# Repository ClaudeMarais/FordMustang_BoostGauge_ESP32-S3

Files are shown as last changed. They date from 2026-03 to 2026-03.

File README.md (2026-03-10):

# Boost Guage for Ford Mustang using ESP32-S3
 
An Arduino project boost gauge for a 2016 Ford Mustang Ecoboost. OBD2 data is used to display turbo boost pressure, current gear, vehicle speed and a shift indicator graph.

NOTE: It's recommended to disconnect the device if the car won't be driven for more than a week.

Car data like boost pressure, RPM, vehicle speed and current gear can be retrieved from the car's high speed CAN bus via the OBD2 port. The ESP32-S3 has a built-in CAN controller, so we connect a SN65HVD230 CAN bus transceiver to the ESP32-S3 which communicates on the high speed bus. Showing something on a display is a blocking operation, i.e. while the display is updating, you can't collect the latest car data. Luckily the ESP32-S3 has two cores, therefore we use one core to continuously read CAN frames with car data while updating the display on the other core.

The OBD2 connector has an always-on 12V pin where the device will be powered from. Since it's always on, it will unnecessarily draw power when the car is turned off. One option would be to just always unplug the device when not driving, another might be to add a button to the device to manually switch it on/off. In this project, we simply detect if the car is turned on and if not, we put the device into a lite sleep mode by reducing the processor clock speed to 40Mhz and switching off the display using a mosfet. For some reason switching in and out of actual deep sleep mode drains the car's battery, it's probably waking up some electronic components in the car? When we detect that the car is on, the processor is switched back to 240MHz and the dispay is switched on again.

Below is some power information when the device is connected together with a BAMA ECU tuner logger device, which also draws power and monitors when the car switches on.

| Microcontroller Setup | Power | Notes  | 
| ---|---|---|
| 240MHz with the display on | 125mA @ 5.12V  | |
| 240MHz with display off | 38mA @ 5.1V | |
| 80Mhz with display off | 29mA @ 5.1V | | 
| 40Mhz with display off | 22mA @ 5.1V | SN65HVD230 requires 80Mhz to operate reliably  | 
| 40/80MHz cycle (3s at 40MHz, 1s at 80MHz) | ~24mA avg @ 5V | Current idle mode |
| Deepsleep with display off | ~7mA @ 5.12V | Drains car battery 0.18V per hour | 

Estimated daily drain from the car's 12V battery (assuming 85% buck converter efficiency):

| Mode | 5V current | 12V current | Daily drain | Days to 50% (60Ah battery) |
|---|---|---|---|---|
| 240 MHz display off | 38 mA | 18.6 mA | 447 mAh | 67 days |
| 80 MHz constant | 29 mA | 14.2 mA | 341 mAh | 88 days |
| 40 MHz constant | 22 mA | 10.8 mA | 259 mAh | 116 days |
| 40/80 MHz cycle (current) | ~24 mA | 11.6 mA | 279 mAh | 107 days |

NOTE: It's fun to tinker with your car, but there is always a chance to mess things up. I won't be liable if for some reason you damage your car.

NOTE: The CAN IDs used in this project specifically work with a 2016 Ford Mustang Ecoboost. The same IDs might not work on other models, you'll have to research what PIDs work with your own car.

Some tips:
 - Diagrams of OBD2 pins are normally shown for the female connector in your car. Don't forget that those pins are in swapped/mirrored positions on the male connector.
 - The OBD2 connector has an "always on" 12V pin. Make sure the wire connecting to that pin on your male connector isn't exposed so that it cannot touch other wires!
 - I tried multiple pins on the ESP32-S3 to connect to the SN65HVD230, but only D4/D5 worked for me. Coincidentally these are also the SDA/SCL pins.
 
Hardware:
 - XIAO ESP32-S3
 - 12V to 5V Voltage regulator
 - SN65HVD230 CAN bus transceiver
 - ILI9341V SPI display, 2.8 inch 240x320 Capacitive Touch Screen
 - AO3401 A19T P-Channel Mosfet (30V 4.2A RDS 50mΩ)
 - 220 Ohm Resistor
 - 2.2K Ohm Resistor
 - Magnetic Pogo Pin Connector
 - OBD2 Connector
 - USB Data Cable
 
Arduino libraries used:
 - ESP32-TWAI-CAN: https://github.com/handmade0octopus/ESP32-TWAI-CAN
 - ArduinoGFX: https://github.com/moononournation/Arduino_GFX

If you are unfamiliar with Arduino, it’s pretty simple and there is a multitude of small tutorials on the internet. At a high level, you will need to:
-	Install the Arduino IDE - https://www.arduino.cc/en/software
-	Configure Arduino IDE for ESP32 - https://randomnerdtutorials.com/installing-esp32-arduino-ide-2-0/
-	Install the two libraries mentioned above - https://docs.arduino.cc/software/ide-v1/tutorials/installing-libraries/
-	Try out the most simple ESP32-S3 app to switch on its onboard LED - https://youtu.be/JlnV3U3Rx7k?si=xF3rMG3LD-cYAaQe

--------------------------------

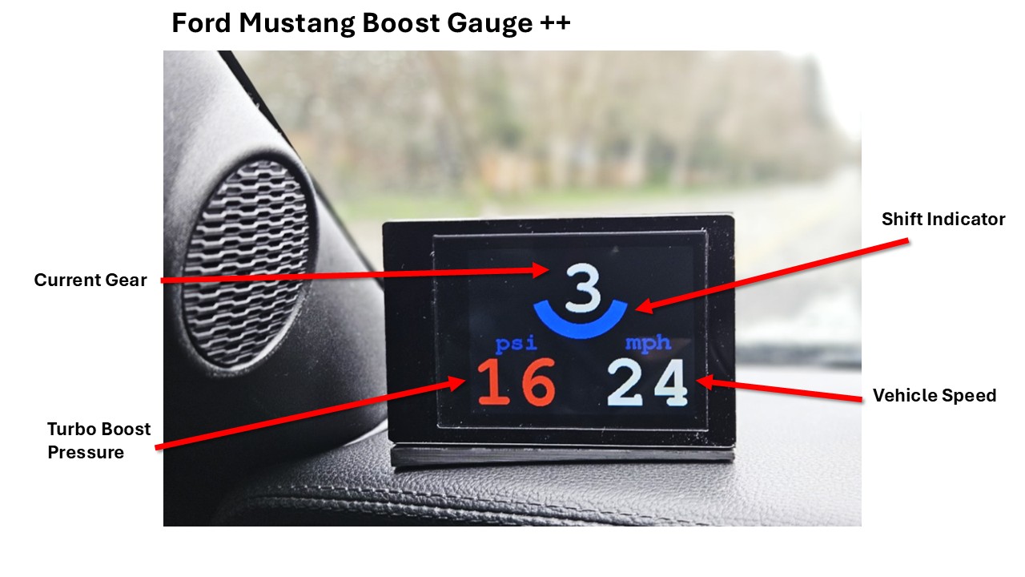
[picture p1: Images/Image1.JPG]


--------------------------------

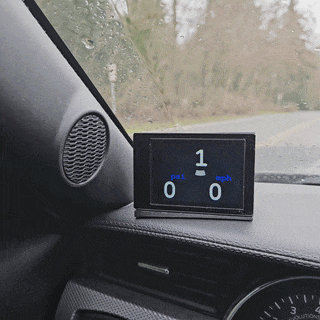
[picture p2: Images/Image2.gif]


--------------------------------

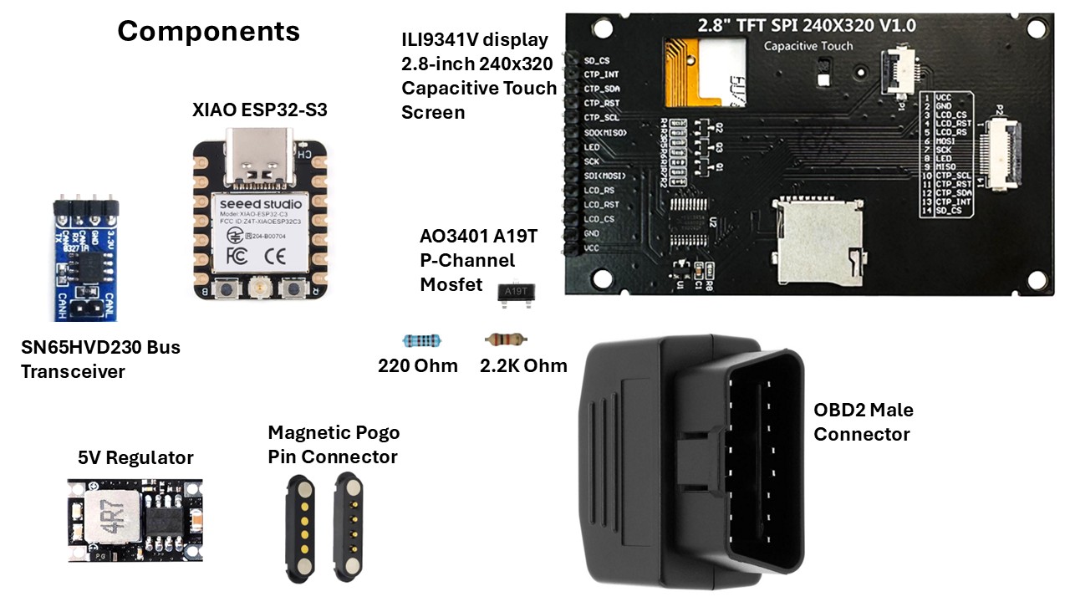
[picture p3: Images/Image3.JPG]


--------------------------------

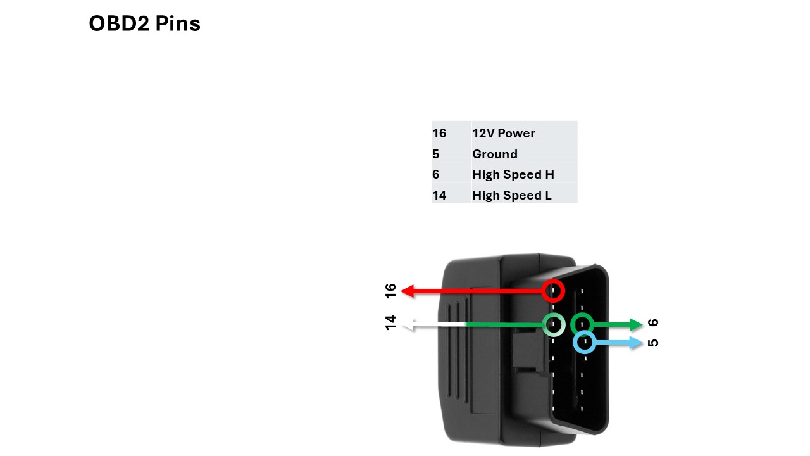
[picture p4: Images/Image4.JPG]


--------------------------------

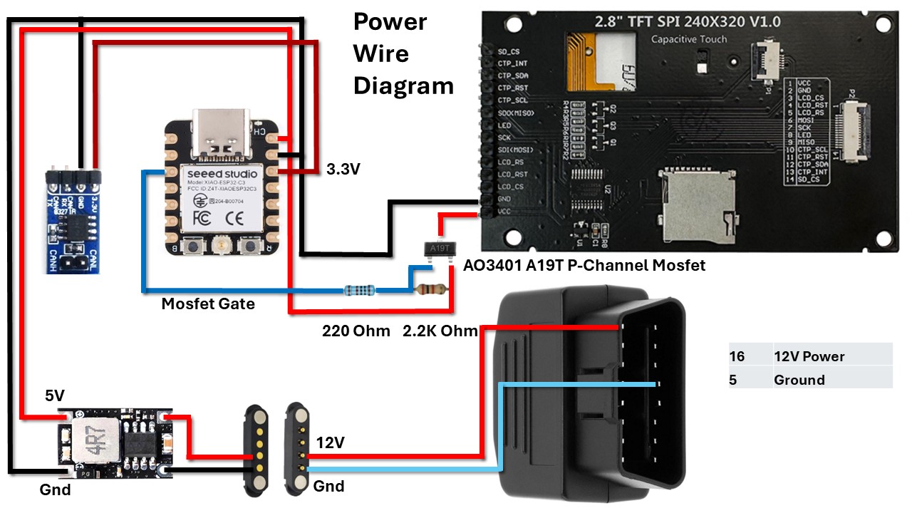
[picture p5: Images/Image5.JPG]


--------------------------------

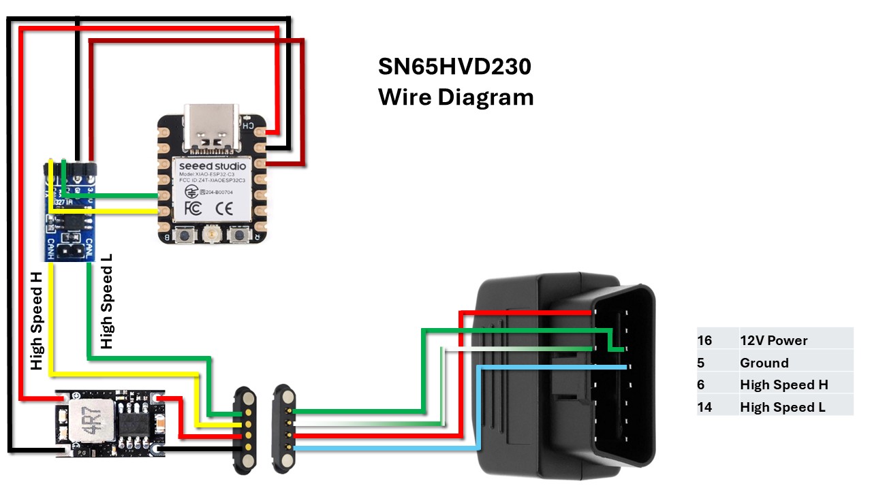
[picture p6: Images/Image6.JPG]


--------------------------------

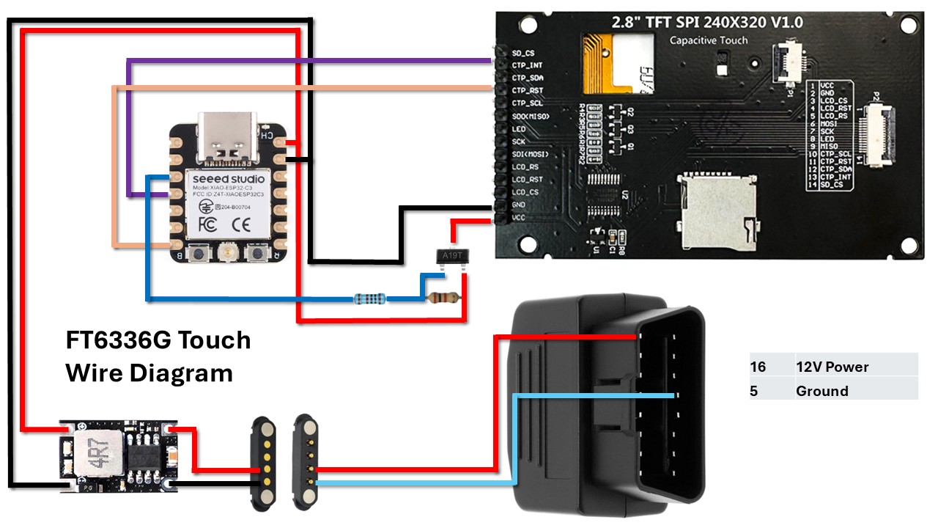
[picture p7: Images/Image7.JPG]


--------------------------------

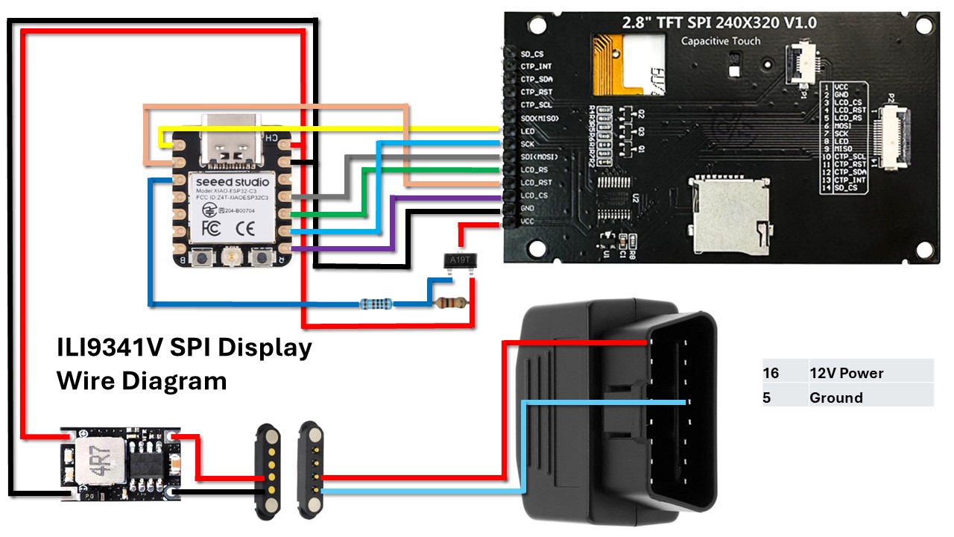
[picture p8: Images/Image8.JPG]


--------------------------------

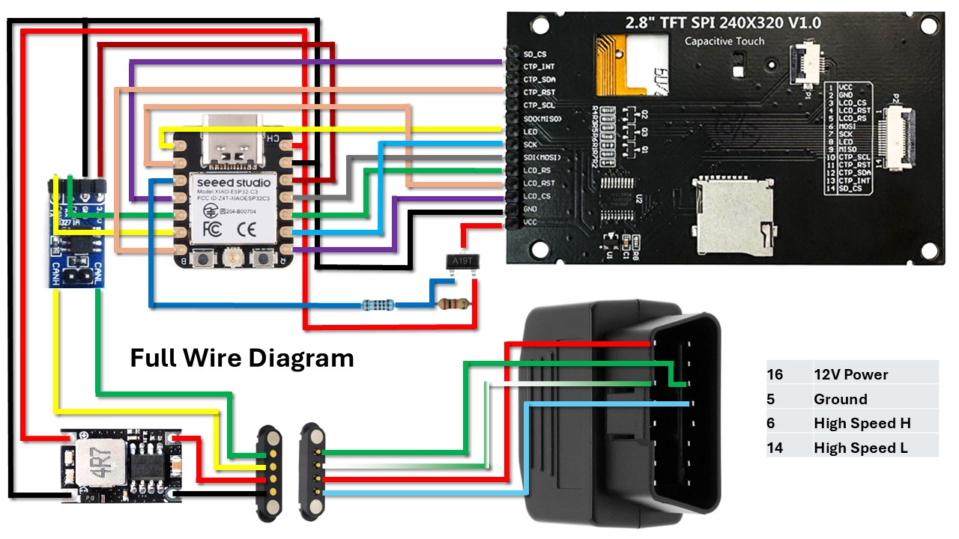
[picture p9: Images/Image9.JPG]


--------------------------------

You will need about 1.5m of wiring to reach from the car's OBD2 connector up to the windshield of the car. Only four OBD2 wires are required to reach the device, two for power and two for the high speed CAN bus communication. I used three different cables for this. First, an OBD2 splitter so that another device, e.g. a tuner device, can be attached while this device is used. Then I soldered a long USB data cable to the OBD2 connector cable. Make sure that you specifically buy a data cable and not a charging cable, since a charging cable won’t have extra data wires.

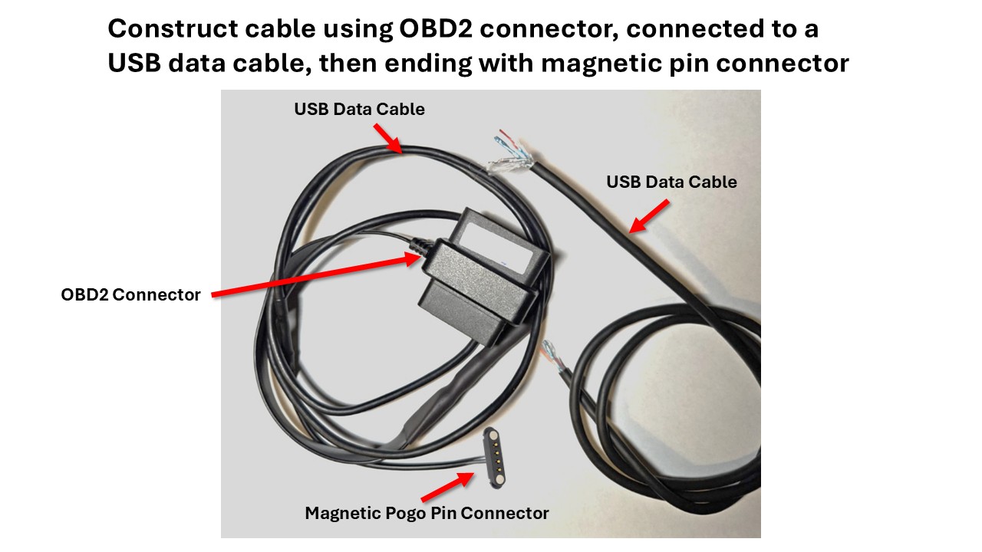
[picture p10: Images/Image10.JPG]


--------------------------------

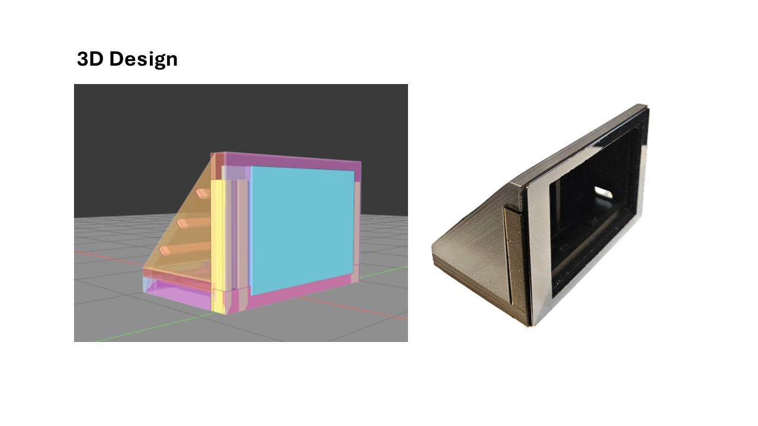
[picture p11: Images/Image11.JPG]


--------------------------------

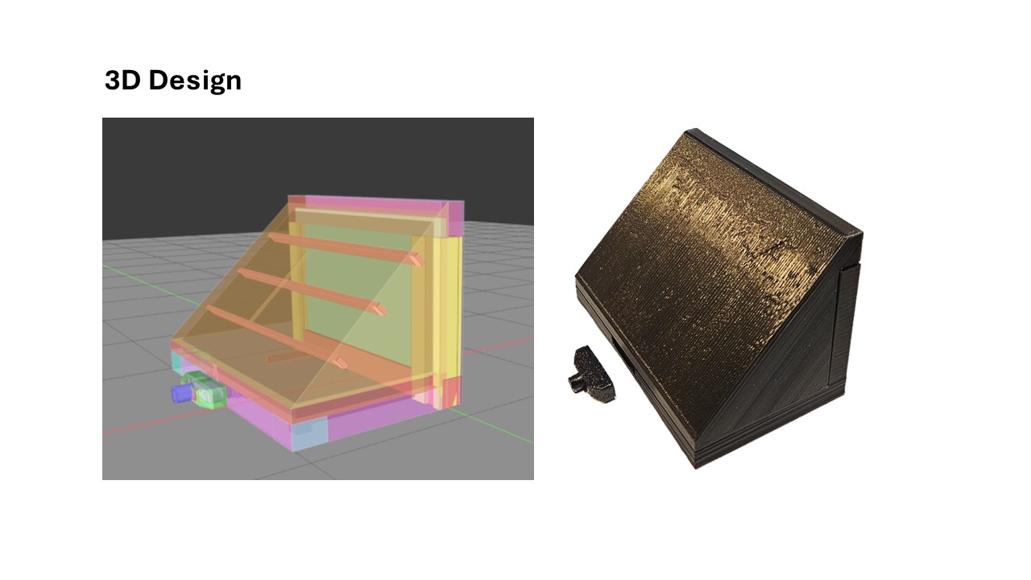
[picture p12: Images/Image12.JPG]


--------------------------------

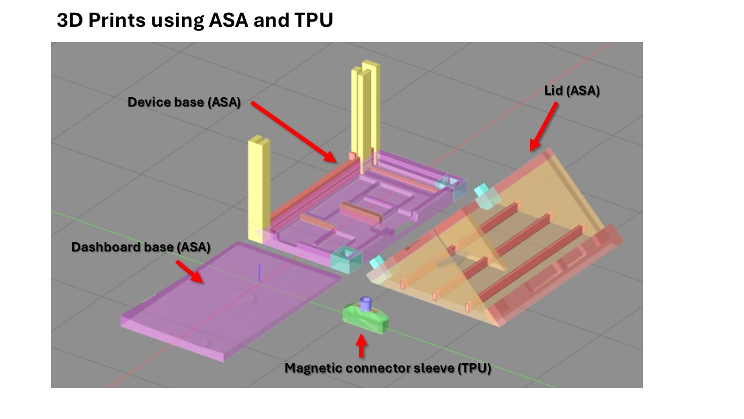
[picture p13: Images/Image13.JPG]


--------------------------------

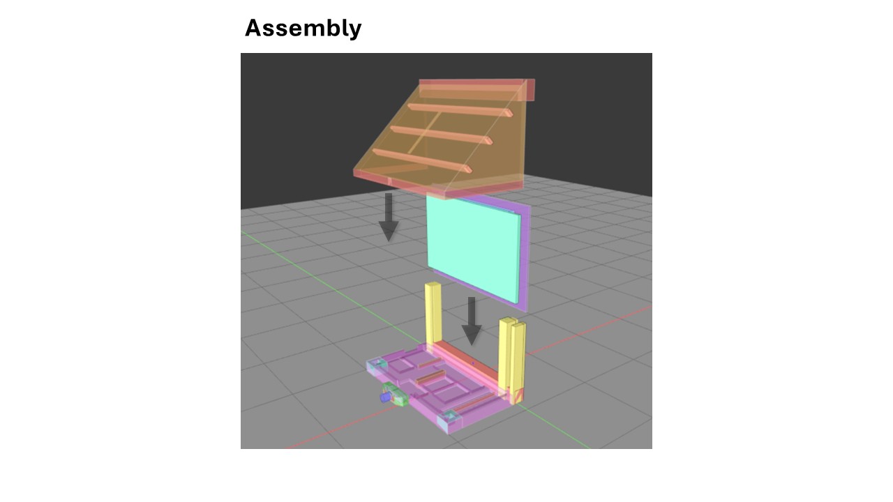
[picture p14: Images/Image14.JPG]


--------------------------------

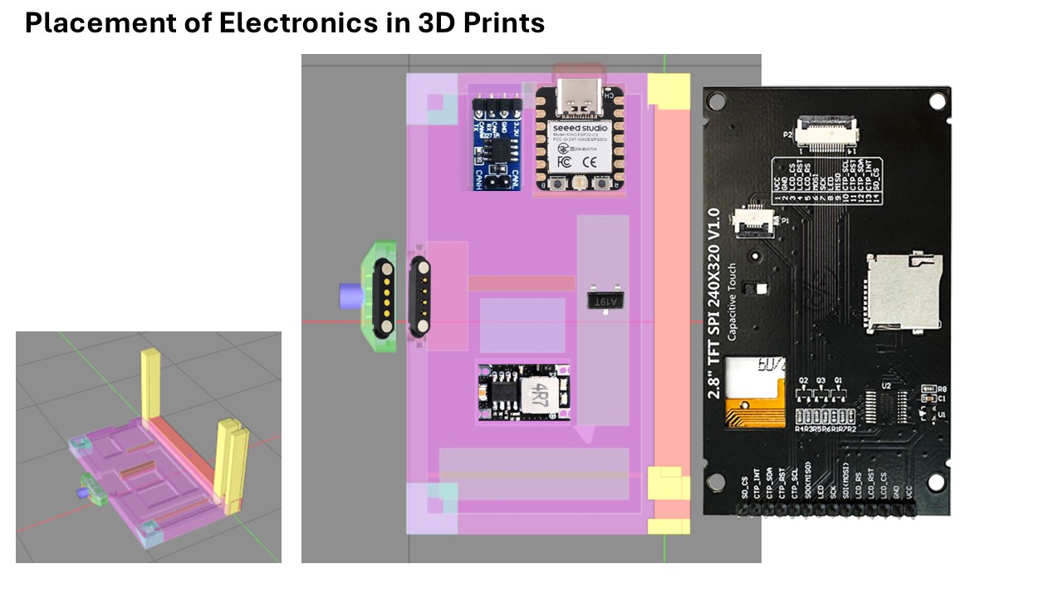
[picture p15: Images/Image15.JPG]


--------------------------------

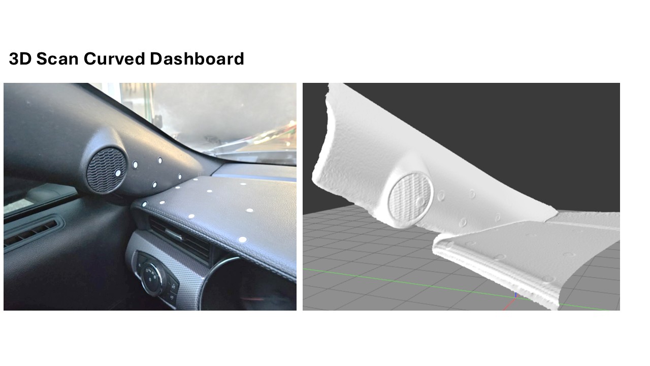
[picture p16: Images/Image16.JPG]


--------------------------------

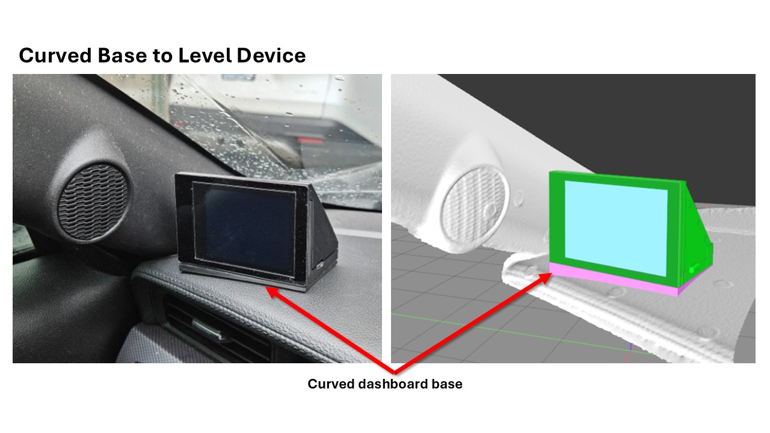
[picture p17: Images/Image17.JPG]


--------------------------------

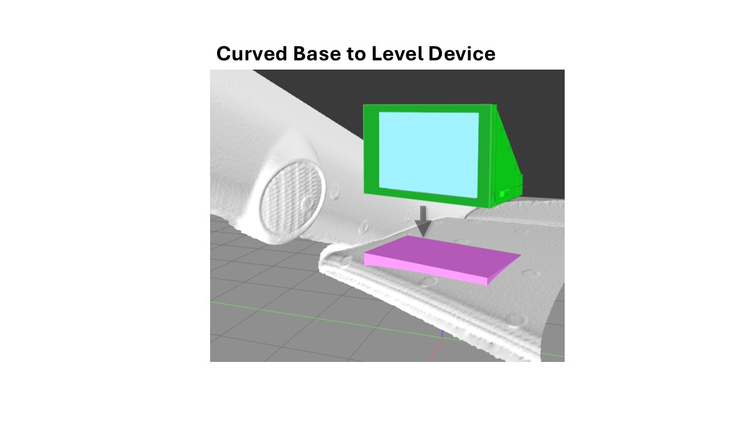
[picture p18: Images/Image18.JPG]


--------------------------------

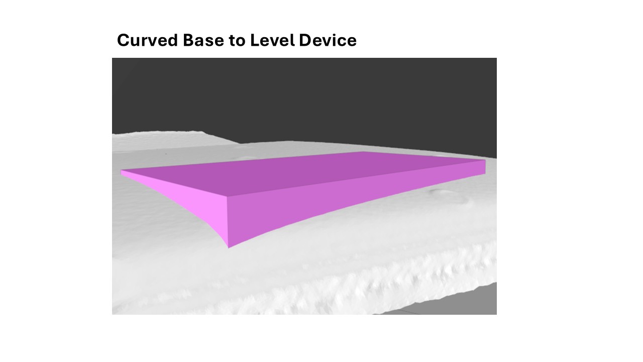
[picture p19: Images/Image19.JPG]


--------------------------------

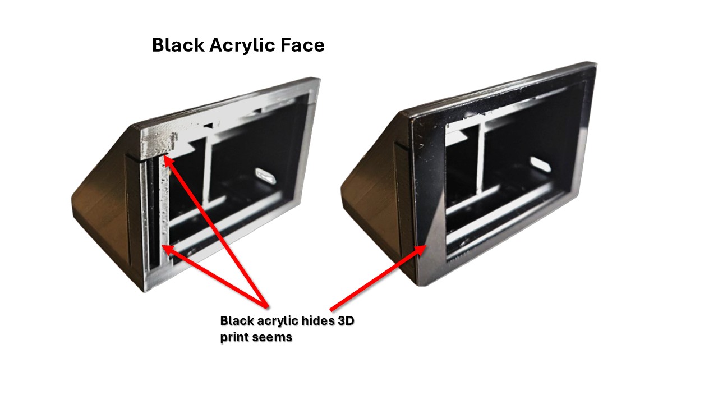
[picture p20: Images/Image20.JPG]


--------------------------------

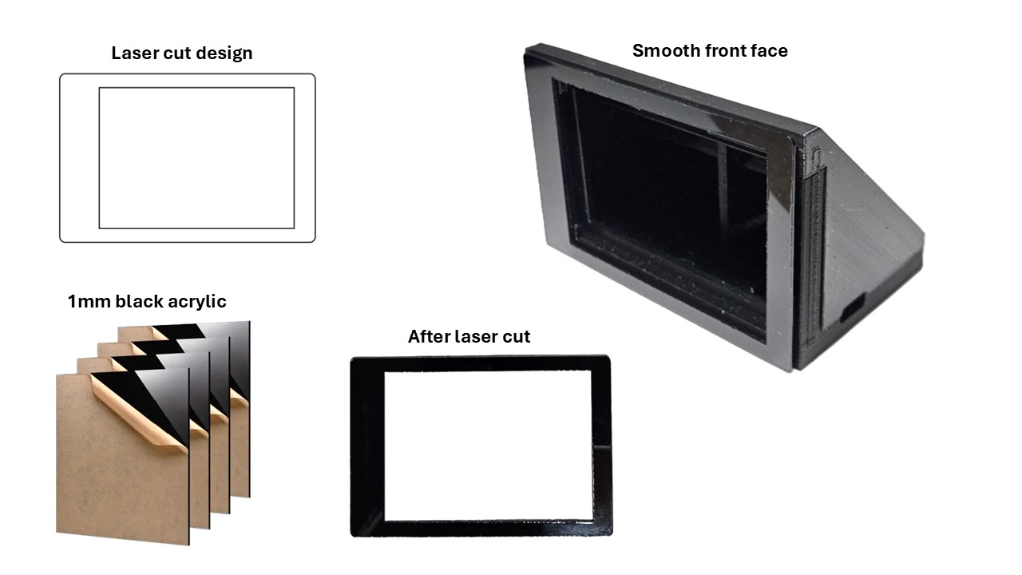
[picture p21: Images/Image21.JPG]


--------------------------------

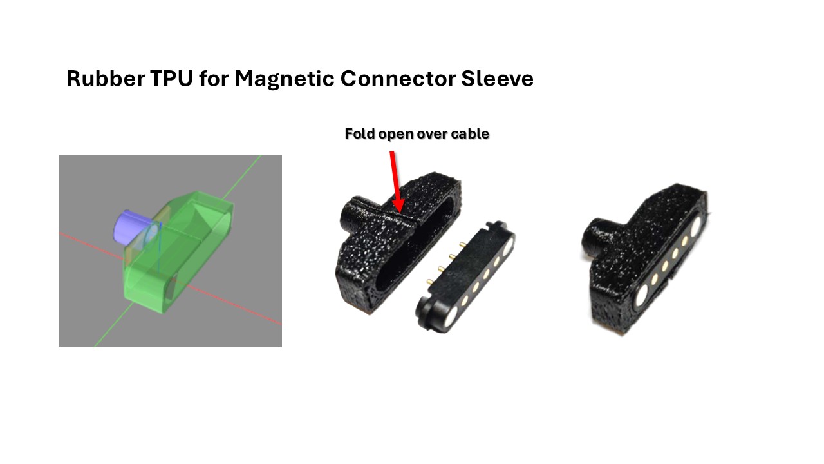
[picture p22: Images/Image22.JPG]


--------------------------------

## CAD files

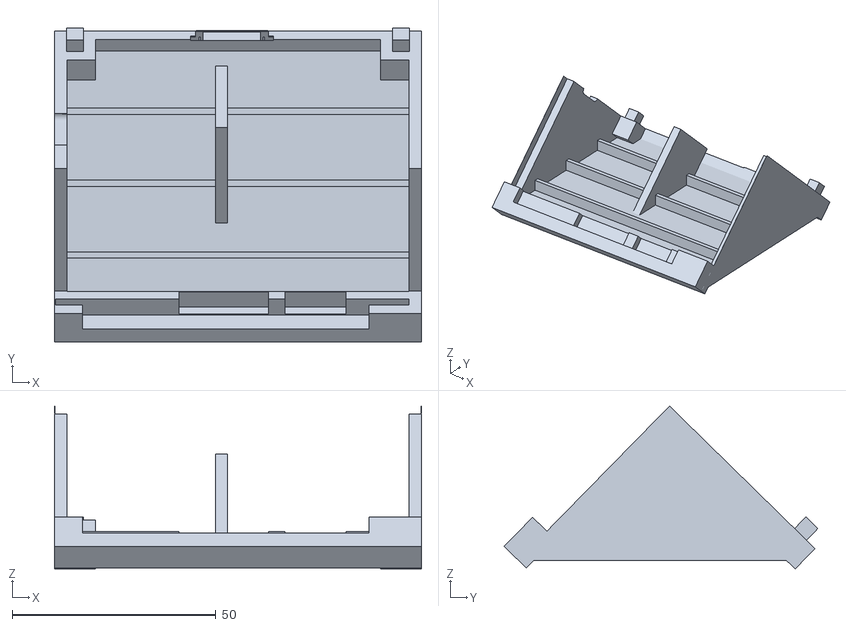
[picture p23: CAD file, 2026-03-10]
3DModels/Lid_ASA.stl
90.0 x 77.0 x 40.0

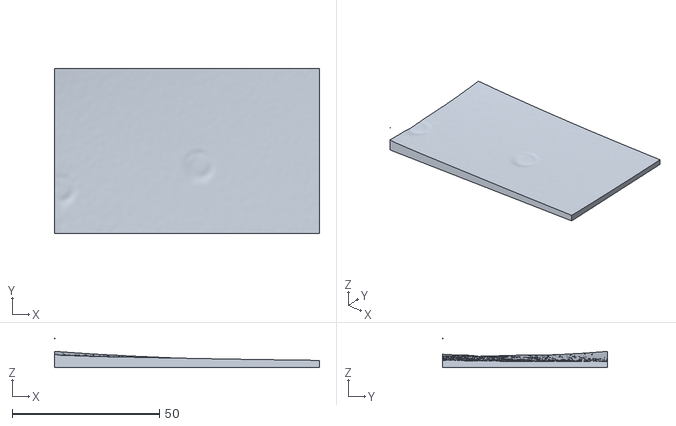
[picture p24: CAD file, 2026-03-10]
3DModels/DashboardBase._ASA.stl
90.0 x 56.0 x 10.0

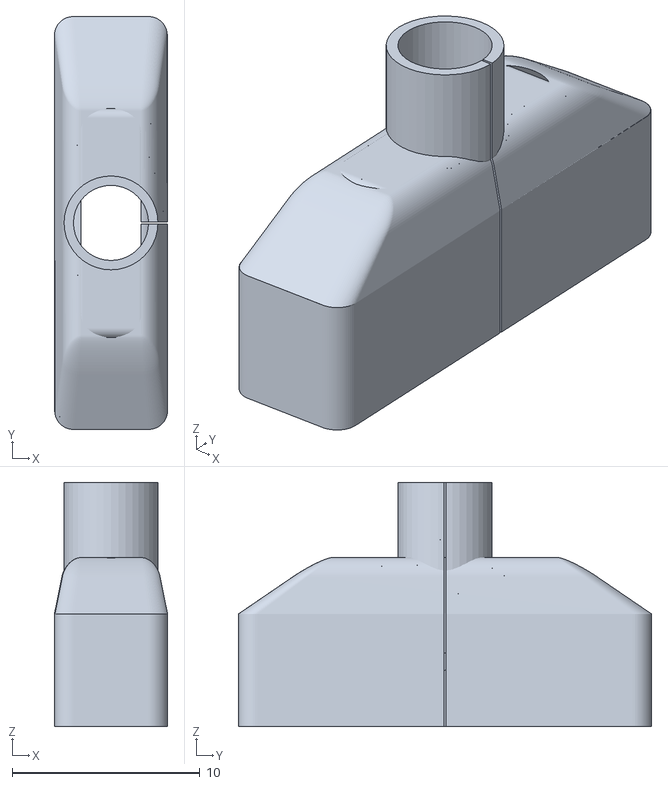
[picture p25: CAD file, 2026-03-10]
3DModels/MagneticConnectorSleeve_TPU.stl
6.03 x 22.0 x 13.0

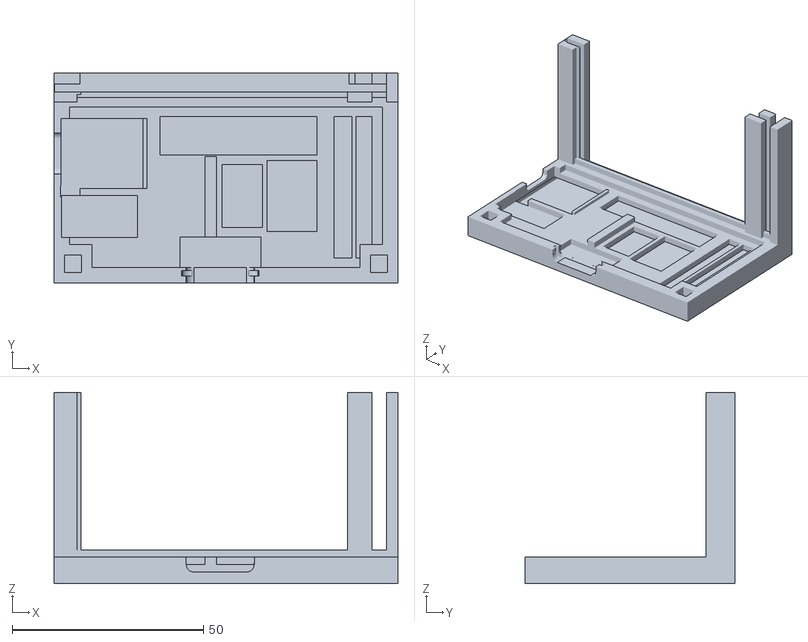
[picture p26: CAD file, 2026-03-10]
3DModels/DeviceBase_ASA.stl
90.0 x 54.9 x 50.0

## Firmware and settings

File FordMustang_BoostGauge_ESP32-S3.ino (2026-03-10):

// An Arduino project boost gauge for a 2016 Ford Mustang Ecoboost. OBD2 data is used to display turbo boost pressure, current gear, vehicle speed and a shift indicator graph.
//
// Hardware:
//    XIAO ESP32-S3
//    12V to 5V Voltage regulator
//    SN65HVD230 CAN bus transceiver
//    ILI9341V SPI display, 2.8 inch 240x320 Capacitive Touch Screen
//    AO3401 A19T P-Channel Mosfet (30V 4.2A RDS 50mΩ)
//    220 Ohm Resistor
//    2.2K Ohm Resistor
//    Magnetic Pogo Pin Connector
//    OBD2 Connector
//    USB Data Cable
//
// Arduino library used:
//    ESP32-TWAI-CAN: https://github.com/handmade0octopus/ESP32-TWAI-CAN
//    ArduinoGFX: https://github.com/moononournation/Arduino_GFX

// The final build should have this commented out
//#define DEBUG 1           // When this is defined, Serial input/output will happen, otherwise not
//#define DEBUG_RPM 1       // Allows for typing in numbers [0..7] in Serial Monitor to emulate RPM
//#define DEBUG_GEAR 1      // Allows for typing in numbers [0..7] in Serial Monitor to emulate current gear. This also requires DISABLE_POWER_SAVING
//#define DEBUG_MPH 1       // Allows for typing in numbers [0..199] in Serial Monitor to emulate vehicle speed in MPH
//#define DEBUG_PSI 1       // Allows for typing in numbers [0..30] in Serial Monitor to emulate turbo boost PSI

// The final build should have this commented out
// It's sometimes easier to debug without the device going into power save mode
//#define DISABLE_POWER_SAVING 1

#include "Shared.h"
#include "CollectCarData.h"
#include "DisplayInfo.h"
#include "HandleLowPowerState.h"


void setup()
{
  pinMode(LED_BUILTIN, OUTPUT);
  digitalWrite(LED_BUILTIN, LOW); // Turn on-board LED on

#ifdef DEBUG
  Serial.begin(115200);
  delay(200);
  Serial.printf("\n\n********* OBD2 Display for Ford Mustang using ESP32-S3 *********\n\n");
#endif

  // Device boots with 240Mhz clock speed. To save power we'll switch to 40Mhz, but just in case the device goes into a
  // reboot loop because of the lower clock, we delay for a few seconds, which will give time to reflash the program
  DebugPrintf("Clock frequency = %d\n", getCpuFrequencyMhz());
  DebugPrintf("Wait 4 seconds just in case device crashes with %dMHz\n", ClockSpeed_LiteSleep);
  delay(4000);

  // Setup the CAN transceiver to receive CAN frames 
  SetupCollectCarData();

  // Wait until the car turns ON
  WaitForCarToTurnOn();

  // Create task that will display info using ESP32-S3 core 0
  xTaskCreatePinnedToCore(DisplayInfo, nullptr, 1024 * 128, nullptr, 1, &g_TaskDisplayInfo, 0);
}

void loop()
{
  CollectCarData();
  CheckIfCarIsStillOn();
}

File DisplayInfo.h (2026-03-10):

// Display info on a ILI9341V SPI display, 2.8 inch 240x320 Capacitive Touch Screen

#ifndef _DISPLAY_INFO
#define _DISPLAY_INFO

#include <Arduino_GFX_Library.h>
#include "FreeMonoBold54pt7b.h"
#include "FreeMonoBold18pt7b.h"

// Setup gfx library for the ILI9341 display
Arduino_DataBus* bus = new Arduino_ESP32SPI(ILI9341_DC, ILI9341_CS, ILI9341_SCK, ILI9341_MOSI, ILI9341_MISO);
Arduino_GFX* gfx = new Arduino_ILI9341(bus, ILI9341_RST, 0, true);
bool bIsDisplayOn = false;

// Define a simple shift indicator based only on RPM. It would be better to setup something using dyno numbers, looking at torque, etc.
struct ShiftIndicatorLights
{
  int32_t EngineRPM;
  uint16_t Color;
};

const int32_t NumLights = 5;
const int32_t ShiftNowIndex = 0;  // Index into shiftIndicatorLights for ideal shift time, i.e. when the indicator turns red
const ShiftIndicatorLights shiftIndicatorLights[NumLights] = { {5800, RGB565_RED}, {4500, RGB565_YELLOW}, {3000, RGB565_GREEN}, {1500, RGB565_BLUE}, {0, RGB565_DARKGREY} };

const int32_t MaxRPM  = 6800;               // Max RPM to show on LCD
const int32_t Reverse = -1;                 // Define Reverse as a special gear number
const int32_t Park    = -2;                 // Define Park as a special gear number
int32_t  previousGear = -12;                // A randomly chosen initial number
uint16_t previousGearColor = RGB565_WHITE;
int32_t  previousSpeed = -1;                // Previous speed value for efficient updating
uint16_t previousSpeedColor = RGB565_WHITE;
int32_t  previousTurboBoost = -999;         // Previous turbo boost value for efficient updating
uint16_t previousTurboBoostColor = RGB565_WHITE;

// Peak-hold for turbo boost: holds the max reading for a short time after boost drops (e.g. gear shift)
const unsigned long BoostPeakHoldMs = 500;   // How long to hold the peak value (ms)
int32_t  boostPeakValue = 0;                 // Current peak boost being held
unsigned long boostPeakTime = 0;             // millis() when the peak was first recorded
bool prevAboveShiftThreshold = false;        // Tracks whether RPM was above shift-now threshold last frame

// Night mode state - triggered by CAN 0x3B3 Day_Night_Status signal
bool g_NightMode = false;

// Dim a RGB565 color for night mode (reduces brightness to ~35%)
uint16_t DimColor(uint16_t color)
{
  if (!g_NightMode)
  {
    return color;
  }

  uint8_t r5 = (color >> 11) & 0x1F;
  uint8_t g6 = (color >> 5) & 0x3F;
  uint8_t b5 = color & 0x1F;
  r5 = (r5 * 35) / 100;
  g6 = (g6 * 35) / 100;
  b5 = (b5 * 35) / 100;

  return (r5 << 11) | (g6 << 5) | b5;
}

// Interrupt handler for when touch was detected on the screen
static volatile uint8_t touched = false;
static volatile unsigned long touchedTime = 0;
void ft6336IntHandler(void)
{
  touched = true;
  touchedTime = millis();
}

// g_CurrentCarData is populated by the SN65HVD230 transceiver on another ESP32-S3 core. Since the data needs to be thread safe, we keep a
// local copy of the data on this thread, copying it safely using g_SemaphoreCarData
CarData carData;

// Make a local copy of car data that was gathered on the other ESP32-S3 core
void CopyCarData()
{
  if (xSemaphoreTake(g_SemaphoreCarData, pdMS_TO_TICKS(100)) != pdTRUE)
  {
    return;
  }

  memcpy(&carData, &g_CurrentCarData, sizeof(CarData));
  xSemaphoreGive(g_SemaphoreCarData);

  // If Neutral, then check if we're in Park, since we'd rather display "P" than "N" when in Park
  if (carData.CurrentGear == 0 &&
      carData.GearboxMode == GearboxMode::P)
  {
    carData.CurrentGear = Park;
  }
}

// Turn power for display ON
void TurnMosfetSwitchOn()
{
  DebugPrintln("Turn Mosfet switch ON");
  pinMode(MOSFET_GATE, OUTPUT);
  digitalWrite(MOSFET_GATE, LOW);   // Gate = 0V
}

// Turn power for display OFF
// IMPORTANT: A 3.3V HIGH from the ESP32 pin is NOT enough to turn off a PMOS whose source is at 5V
//            (3.3V gate gives Vgs = -1.7V → still partially ON)
// Correct control method with a 5V source:
//   - Use a 2.2K pull-up resistor from Gate → Source (5V)
//   - Drive the ESP32 pin in "open-drain style":
//            pinMode(PIN, INPUT);   // Hi-Z, pull-up forces Gate = 5V
void TurnMosfetSwitchOff()
{
  DebugPrintln("Turn Mosfet switch OFF");
  //pinMode(MOSFET_GATE, OUTPUT);
  //digitalWrite(MOSFET_GATE, HIGH);
  pinMode(MOSFET_GATE, INPUT);
}

// Draw static labels that never change (called once during initialization)
void DrawStaticLabels()
{
  const int16_t width = 320;
  const int16_t height = 240;
  const int16_t largeFontSize = 54;
  const int32_t bottom = height - (largeFontSize / 4);

  gfx->setFont(&FreeMonoBold18pt7b);
  gfx->setTextSize(1);

  int16_t mphLabelX = width - (int16_t)(largeFontSize * 2.4f) + largeFontSize - 20;
  int16_t mphLabelY = bottom - (largeFontSize / 2) - (18 * 3);
  int16_t psiLabelX = 0 + largeFontSize - 18;
  int16_t psiLabelY = bottom - (largeFontSize / 2) - (18 * 3);

  // Erase old labels (harmless on first call since screen is already black)
  gfx->setTextColor(RGB565_BLACK);
  gfx->setCursor(mphLabelX, mphLabelY);
  gfx->printf("mph");
  gfx->setCursor(psiLabelX, psiLabelY);
  gfx->printf("psi");

  // Draw labels with current color (dimmed in night mode)
  gfx->setTextColor(DimColor(RGB565_NAVY));
  gfx->setCursor(mphLabelX, mphLabelY);
  gfx->printf("mph");
  gfx->setCursor(psiLabelX, psiLabelY);
  gfx->printf("psi");
}

void TurnBacklightOn()
{
  pinMode(ILI9341_BL, OUTPUT);
  digitalWrite(ILI9341_BL, HIGH);
}

void TurnBacklightOff()
{
  pinMode(ILI9341_BL, OUTPUT);
  digitalWrite(ILI9341_BL, LOW);
}

void TurnDisplayOn()
{
  DebugPrintln("TurnDisplayOn()");

  // Turn power on
  TurnMosfetSwitchOn();
  delay(20);

  // Init display
  while (!gfx->begin())
  {
    DebugPrintln("gfx->begin() failed!");
    delay(500);
  }

  TurnBacklightOn();

  bIsDisplayOn = true;

  gfx->fillScreen(RGB565_BLACK);
  gfx->setRotation(3);
  gfx->setTextSize(1);

  pinMode(FT6336_INT, INPUT_PULLUP);
  attachInterrupt(digitalPinToInterrupt(FT6336_INT), ft6336IntHandler, FALLING);

  DrawStaticLabels();
}

void TurnDisplayOff()
{
  DebugPrintln("TurnDisplayOff()");
  detachInterrupt(digitalPinToInterrupt(FT6336_INT));
  gfx->fillScreen(RGB565_BLACK);
  gfx->displayOff();

  TurnBacklightOff();

  // Set all display pins to INPUT to minimize power consumption and avoid floating outputs
  pinMode(ILI9341_SCK, INPUT);
  pinMode(ILI9341_MOSI, INPUT);
  pinMode(ILI9341_CS, INPUT);
  pinMode(ILI9341_DC, INPUT);
  pinMode(ILI9341_RST, INPUT);
  pinMode(ILI9341_BL, INPUT);
  pinMode(FT6336_INT, INPUT);
  pinMode(FT6336_RST, INPUT);

  delay(20);

  TurnMosfetSwitchOff();

  bIsDisplayOn = false;
  delay(100);
}

char GenerateGearText(const int32_t gear)
{
  if ((gear > 0) && (gear <= 8))
  {
    return '0' + gear;
  }
  else
  {
    return (gear == Park) ? 'P' : (gear == Reverse) ? 'R' : (gear == 0) ? 'N' : 'D';
  }
}
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
